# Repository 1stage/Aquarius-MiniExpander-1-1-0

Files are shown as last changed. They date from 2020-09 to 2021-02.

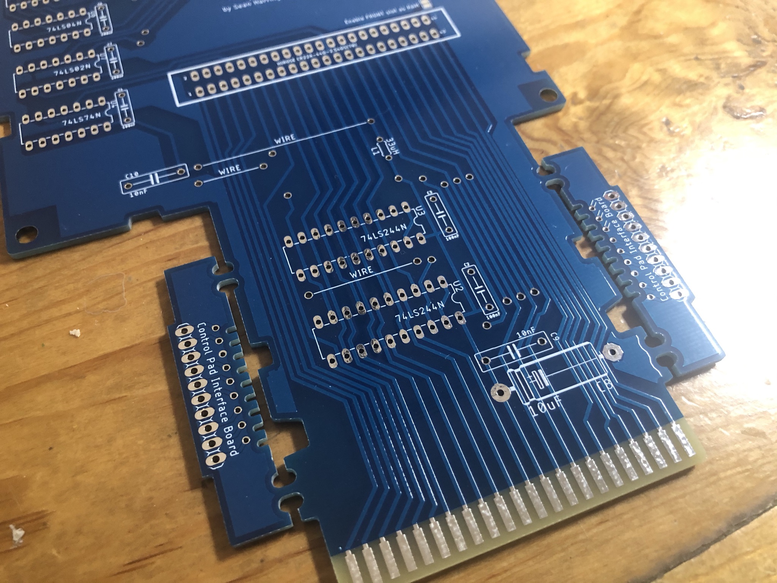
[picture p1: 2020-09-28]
images/IMG_6342.JPEG

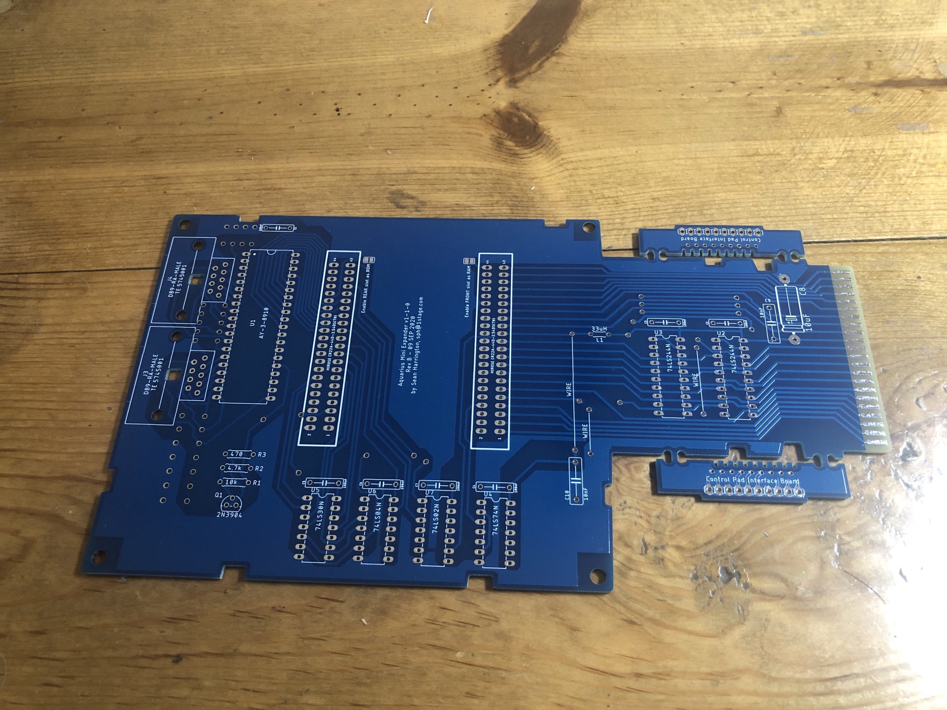
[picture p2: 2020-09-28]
images/IMG_6341.JPEG

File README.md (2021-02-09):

# Aquarius Mini Expander 1-1-0
Aquarius Mini Expander 1-1-0 - Rev C, 14 FEB 2021
 
by Sean P. Harrington, sph@1stage.com, http://aquarius.1stage.com
 
## Background
Since the Aquarius doesn't do much on it's own, and playing games on the chicklet keyboard is annoying, adding the functionality of the Mini Expander is essential. The Mini Expander expands the sounds to three voices, adds both a RAM and cartridge ROM expansion slot, and has ports for the Aquarius control pads. But since many Aquarius users DON'T have easy access to these devices, particularly in Europe, it was essential that this PCB be made available. 

## Purpose
The purpose of this project is to document the stock Aquarius Mini Expander, both in schematic form and in board layout. An excellent document from Radofin exists that records the original schematic for the device, and it was used to verify the components and layout of this project, but there are a few, minor discrepancies that have been corrected based on ACTUAL board layout. 

Also, this board serves as a useful prototype for how the expansion bus can be used on the Aquarius. By observing how the AY-3-8910 sound/IO chip is interfaced to the address and data bus, users who want to create their own expansion device could do so. Since it is already a very simple device (only about 25 components), the large footprint of the board could be improved through smaller SMD components and better trace routing, leaving plenty of room for additional functionality within the original (or modified) Mini Expander case.

To that end, an additional header for AY-3-8910 I/O has been added, along with detailed silkscreen markings on both the new header and the upper Expansion Slot so that hobbyists can experiment with creating their own expansions to the Aquarius. A reminder that the Expansion Slot pins are NOT like GPIO pins on an Arduino or Raspberry Pi. A0 does NOT mean analog pin zero, and D0 does NOT mean digital pin zero (nor any of the others). If you want to create your own I/O procedures, use the IO pins on the AY-3-8910 instead.

## Bill of Materials
https://docs.google.com/spreadsheets/d/1Fgy7V73wTicvzhZblFc1MAg1R4uz7tYPBy140xyRtXA	

## Components
* Aquarius Mini Expander v1-1-0 PCB Rev B, 09 SEP 2020
* Electronic components (listed in BOM above)
* 3D printed parts
  * Aquarius Mini Expander v1-1-0 case BOTTOM
  * Aquarius Mini Expander v1-1-0 case TOP (in development)
  * Aquarius Mini Expander v1-1-0 case TRAP_FRONT (in development)
  * Aquarius Mini Expander v1-1-0 case TRAP_REAR (in development)
* Assembly screws (to be specified later)
* Trap Door springs (to be specified later)
* Trap Door hinges (to be specified later)

## Caveats
* This project does **not incorporate** any new functionality. Users who want to add functionality may fork this project on their own.
  * SD Card read/write is not implemented, such as on the Micro Expander, a project developed by Bruce Abbott
  * A RAM expansion device is not included, such as the 32kb RAM Cartridge, a product developed by Jay Snellen, III
  * A cartridge ROM expansion device is not included, such as the AquariCart, a product developed by Jay Snellen, III
  * Switchable use of ATARI or SEGA joysticks (despite the same DB9 plugs)
* For users who want to use RAM or ROM in either cartridge slot, jumper pads (solder) have been added to connect pin 34 (rear slot) and/or pin 44 (front slot) to GND. Use this at your own discretion, but understand that you can't insert two ROM cartridges and expect them to work. Using two RAM cartridges could theoretically work, but it has not been tested.
* To maintain original layout, the three interconnect wires are not incorporated into the PCB. They are indicated as "WIRE" on the PCB, which should be bridged with 22 gauge solid core, insulated wire.
* The L1 choke/line filter (33uH) is difficult to source. Users may simply bridge this gap with 22 gauge solid core wire, or they can use a 0 ohm ferrite bead.
* Two of the small Control Pad interface boards are included as breakaways on either side of the narrow part of the board. These must be removed before the Mini Expander PCB can fit in the stock plastic shell. These small interface boards are used to transition the nine wires in the joystick cable to the mylar conductive pad used in the Control Pads.

## FAQs
* Where can I get the PCBs?
  * https://www.pcbway.com/project/shareproject/Aquarius_Computer_Mini_Expander_PCB.html
* Will you build me a Mini Expander? I'll pay you!
  * I won't (WAY too much to do), but it's not too difficult to do yourself. Also, there are some in the Aquarius community who can build one for you.
* Where can I get a case for this?
  * 3D print one yourself by exploring the 3d folder of the project. I haven't had time to create the top half (there are some intricate trap-door things to model), but maybe someone in the community will model one to fit?
* What about Control Pads?
  * There is a prototype for the Control Pads within the project, but I haven't had the time to take it beyond the prototype phase. This is open source, so have at it!
* How is this project different from the Micro Expander?
  * Designed by Bruce Abbott, the Aquarius Micro Expander is similar to the Mini Expander in that it has an AY-3-8910 sound chip and a header for Control Pad input (NOT joystick ports, a pin header). The Micro Expander is different in that it has a 32k memory expansion in it, a USB port, a 3.5mm audio port, along with a custom ROM that features a PT3 music player, USB ROM reading access, and a customized version of BASIC. The down side is that it blocks the Expansion Port of the Aquarius, so cartridge-based ROM programs (SNAFU, Nightstalker, D&D etc.) can't be used (unless you have the ROM image to load through USB).
* Why can't I use the A00-A15 expansion pins as analog input/output, or the D00-D15 as digital input/output for my Arduino experiments?
  * First of all, these pins are NOT analog and digital input/output pins! They are DIRECTLY connected to the **address** bus and the **data** bus (hence the A00 or D00 markings). Unless you know how the timings of these busses work, you're more than likely going to damage your Aquarius. If you want to experiment safely with TTL level inputs and outputs, use the IOA0-IOA7 or IOB0-IOB7 pins on the AY-3-8910 header instead.

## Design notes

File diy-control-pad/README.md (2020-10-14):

# DIY Aquarius Control Pad 1-1-0x
DIY Aquarius Control Pad 1-1-0x, 11 OCT 2020
 
by Sean P. Harrington, sph@1stage.com, http://aquarius.1stage.com
 
## Purpose
While reverse engineering the Mini Expander, it became obvious very quickly that there was also a need for easy-to-make Control Pads for the Aquarius. Those, as many of my UK/EU friends have said, are rare as hen's teeth. The stock unit was designed to be SUPER cheap and SUPER easy to crank out in quantity, however, the processes used in making the conductive ink, flexible control boards for the joysticks are not easily recreatable by a casual maker or electronics enthusiast. So I designed these "fugly" control boards using inexpensive, easy to source through-hole tactile switches and LN4148 diodes, a PCB, and a commonly available Atari/Sega joystick extension cable. 

## Components
* DIY Aquarius Control Pad v1-1-0x PCB, 11 OCT 2020
* Electronic components
  * 22 @ 6mm through hole tactile switches
  * 42 @ 1N4148 diodes
* 6 foot / 2 meter Atari/Sega Joystick extension cable
* 3D printed parts
  * DIY Aquarius Control Pad v1-1-0x BASE
  * DIY Aquarius Control Pad v1-1-0x TOP
  * DIY Aquarius Control Pad v1-1-0x DISC
  * DIY Aquarius Control Pad v1-1-0x BUTTONS
* Assembly screws (to be specified later)

## Caveats
* None, right now...

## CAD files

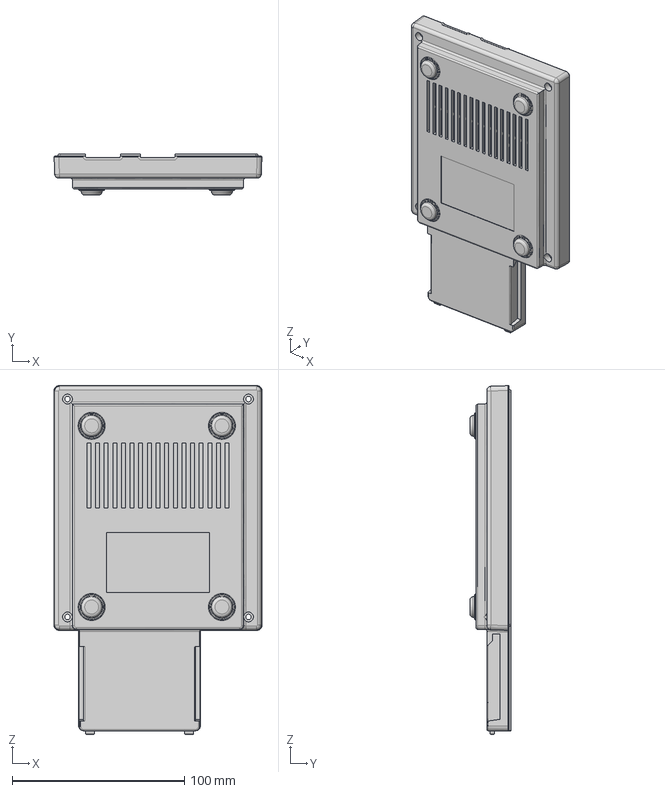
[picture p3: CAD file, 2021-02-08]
3d/v1-1-0 Mini Expander Base v4.iges
120.7 x 24.0 x 202.7 mm

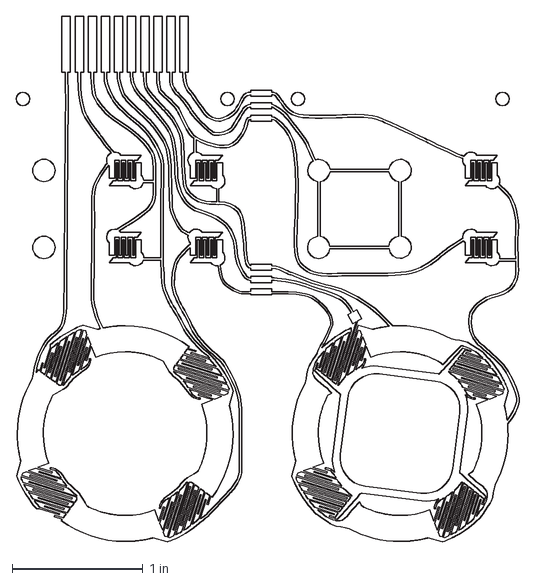
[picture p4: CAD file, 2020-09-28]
artwork/controller_circuit_01b_for_CUT.dxf
3.85 x 4.02 in

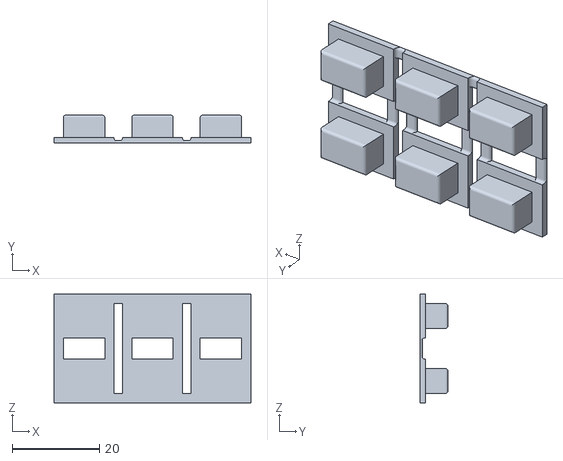
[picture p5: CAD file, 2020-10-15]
diy-control-pad/3d-case/diy_cp_buttons.stl
45.2 x 6.35 x 25.0

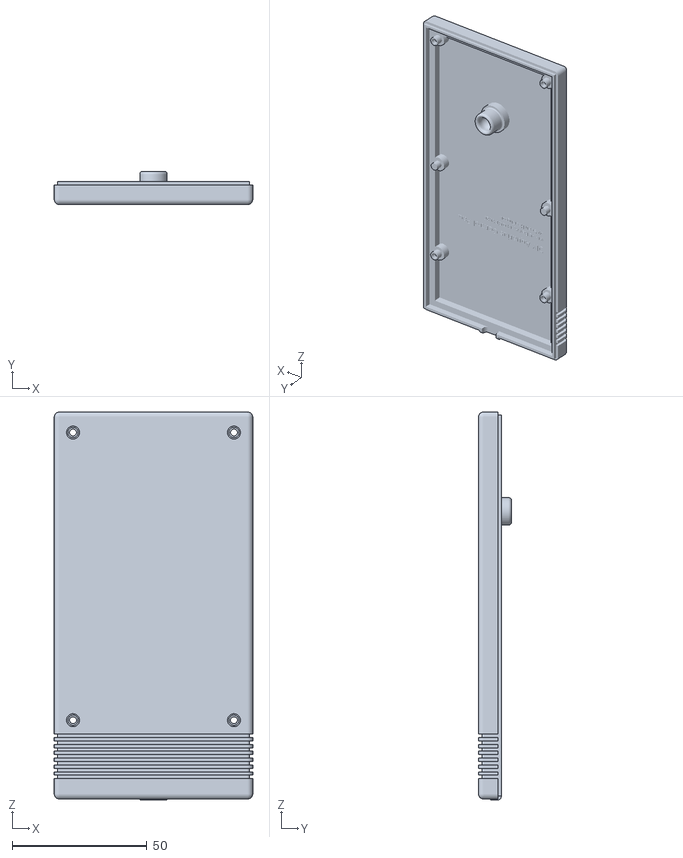
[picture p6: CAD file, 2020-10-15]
diy-control-pad/3d-case/diy_cp_base.stl
73.7 x 12.3 x 143.9

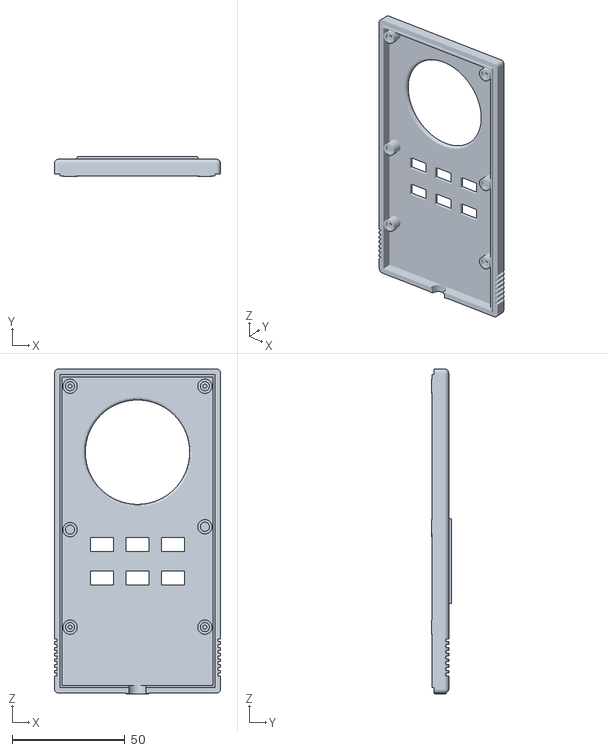
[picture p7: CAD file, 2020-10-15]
diy-control-pad/3d-case/diy_cp_top.stl
73.7 x 8.99 x 143.9

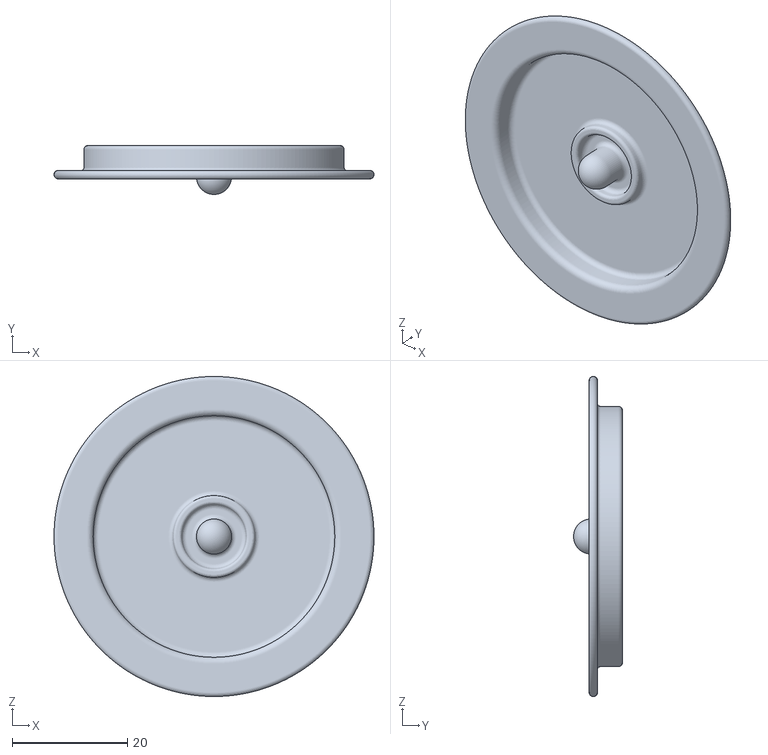
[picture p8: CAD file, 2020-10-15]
diy-control-pad/3d-case/diy_cp_disc.stl
55.5 x 8.48 x 55.5

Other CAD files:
3d/mini_expander_case_BOTTOM.stl

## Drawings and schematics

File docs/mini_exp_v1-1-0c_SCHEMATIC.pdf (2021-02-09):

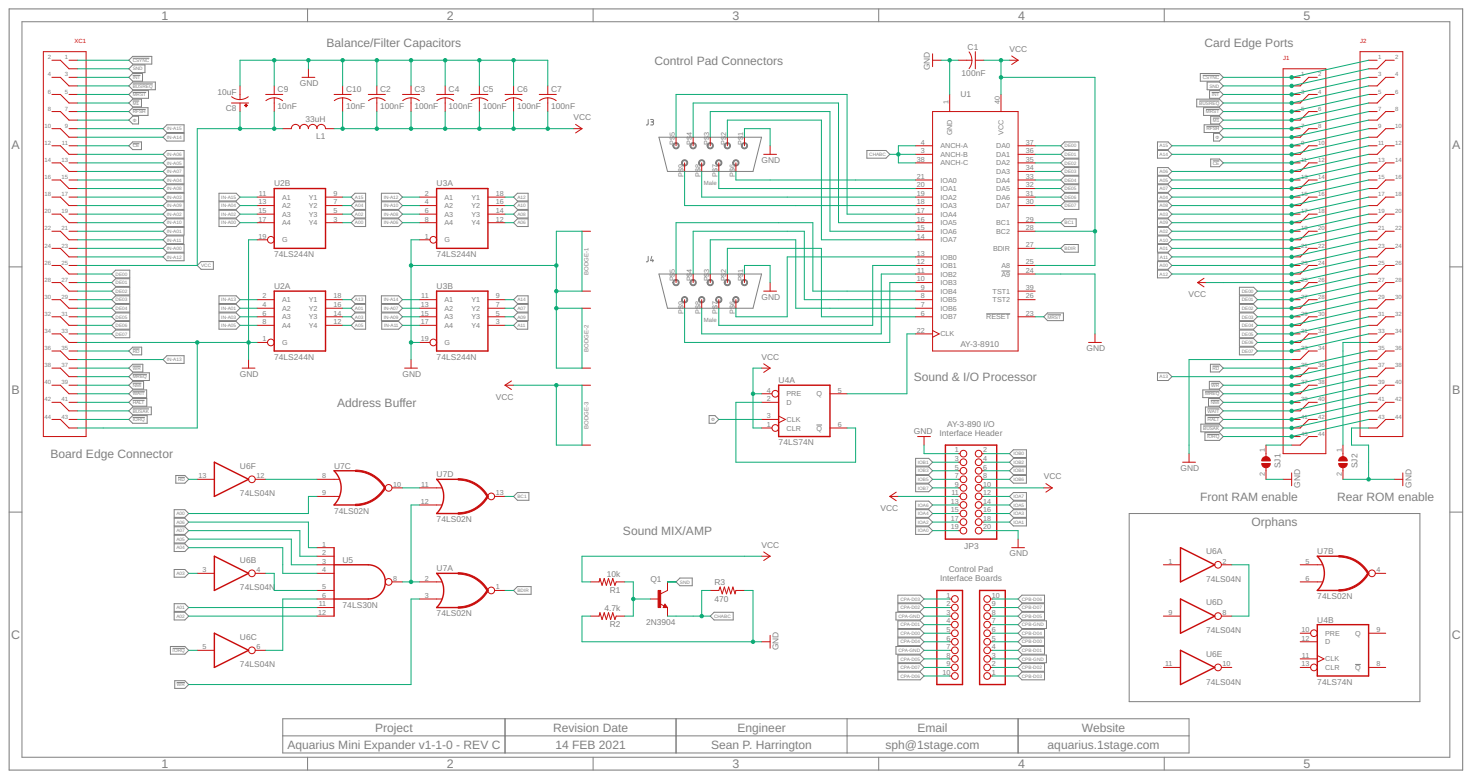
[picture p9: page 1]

CPA-D03 CPA-D02 CPA-GND

CPB-D06 CPB-D07 CPB-D05 CPB-GND

Project | Revision Date | Engineer | Email | Website

Aquarius Mini Expander v1-1-0 - REV C | 14 FEB 2021 | Sean P. Harrington | sph@1stage.com | aquarius.1stage.com

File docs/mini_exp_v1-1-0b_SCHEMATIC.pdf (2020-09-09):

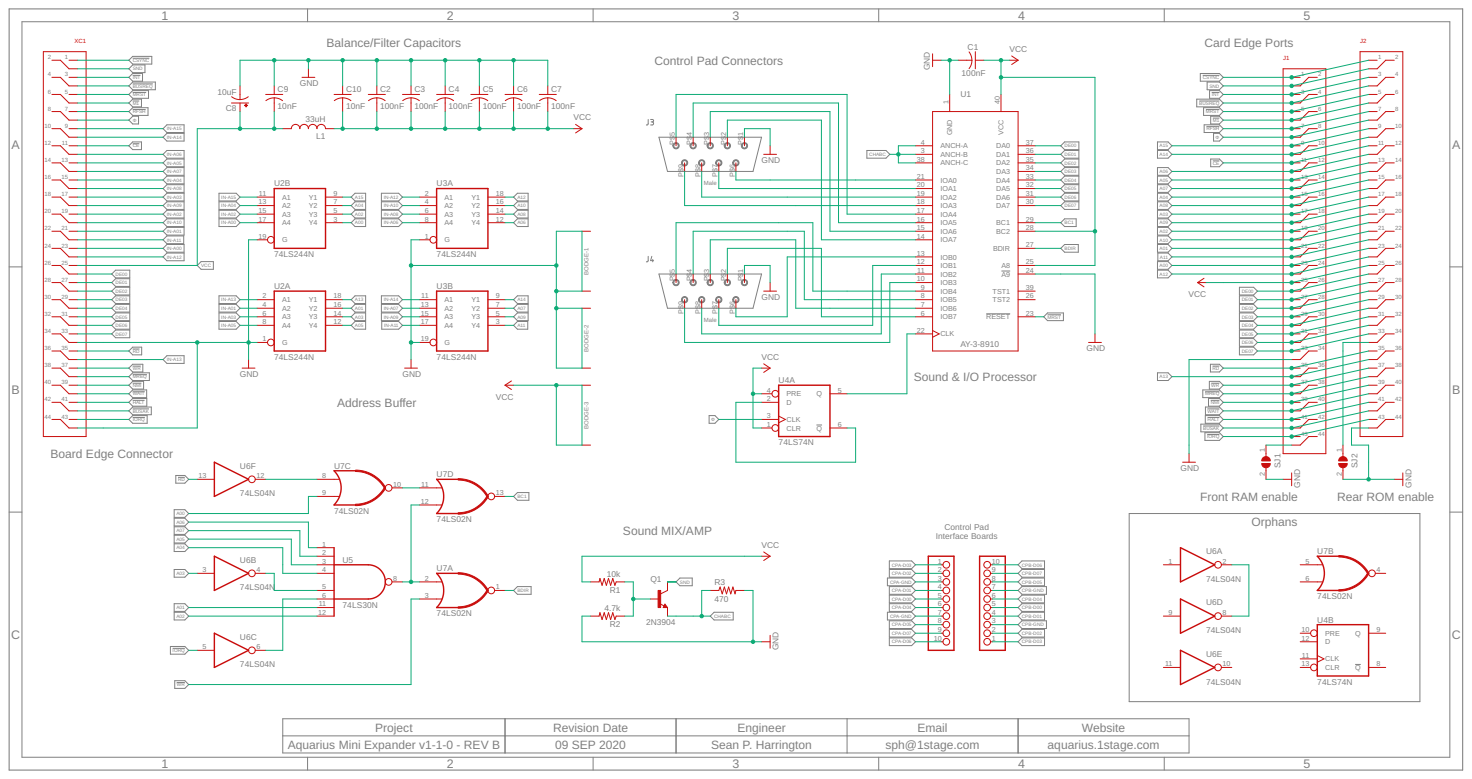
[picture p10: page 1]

CPA-D03 CPA-D02 CPA-GND

CPB-D06 CPB-D07 CPB-D05 CPB-GND

Project | Revision Date | Engineer | Email | Website

Aquarius Mini Expander v1-1-0 - REV B | 09 SEP 2020 | Sean P. Harrington | sph@1stage.com | aquarius.1stage.com

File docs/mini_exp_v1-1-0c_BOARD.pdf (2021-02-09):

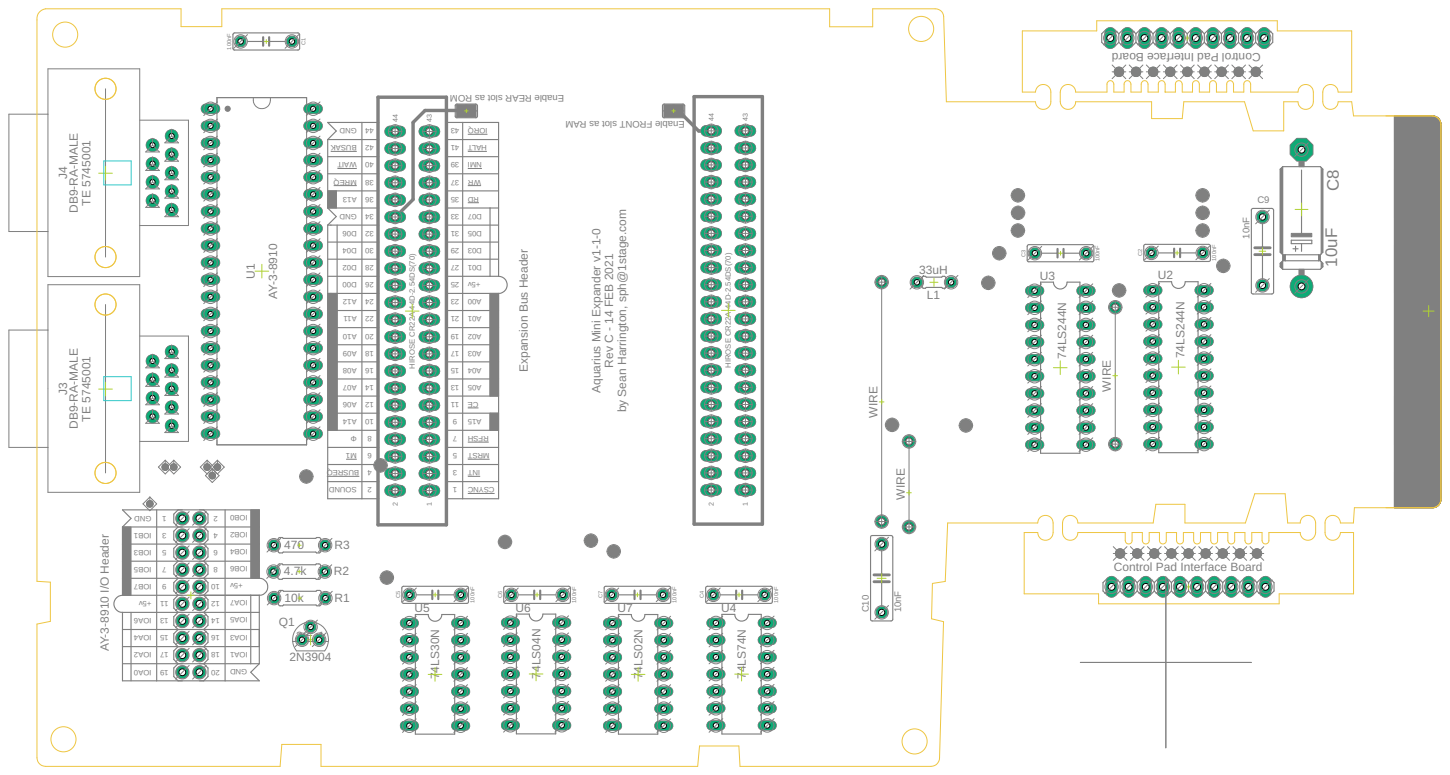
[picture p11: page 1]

Aquarius Mini Expander v1-1-0 Rev C - 14 FEB 2021 by Sean Harrington, sph@1stage.com MORsat ol s RAERel banE MARsat ol s TNORF el banE dr aoB ecafr et nI daPl ort no C Control Pad Interface Board CNYSC TNI TSRM HSFR 51A EC50A 40A 30A 20A 10A 00A v5+ 10 D 30 D 50 D 70 D DRR W I MN TLAH QROI DNUOS 341493735333139272523212917151311197531 4424048363432303826242220281614121018642 QERSUB 1 MΦ 41A 60A 70A 80A 90A 01A 11A 21A 00 D 20 D 40 D 60 D DNG 31A QERM TI A W KASUB DNG 0AOI 91 2AOI 71 4AOI 51 6AOI 31 v5+ 11 7BOI 9 5BOI 7 3BOI 5 1BOI 3 DNG 1 0281614121018642 DNG 1AOI 3AOI 5AOI 7AOI v5+ 6BOI 4BOI 2BOI 0BOI Expansion Bus Header AY-3-8910 I/O Header DB9-RA-MALE TE 5745001 J4 DB9-RA-MALE TE 5745001 J3 21 4443 HIROSE CR22A-44D-2.54DS(70) 21 4443 HIROSE CR22A-44D-2.54DS(70) WIRE WIRE WIRE 2 3 1 U1 AY-3-8910 U3 74LS244N U4 74LS74N U2 74LS244N U7 74LS02N U6 74LS04N U5 74LS30N 10k R1 4.7k R2 470 R3 C8 10uF C1 100nF C3 100nF C2 100nF C5 100nF C6 100nF C7 100nF C4 100nF C9 10nF C10 10nF L1 33uH Q12N3904

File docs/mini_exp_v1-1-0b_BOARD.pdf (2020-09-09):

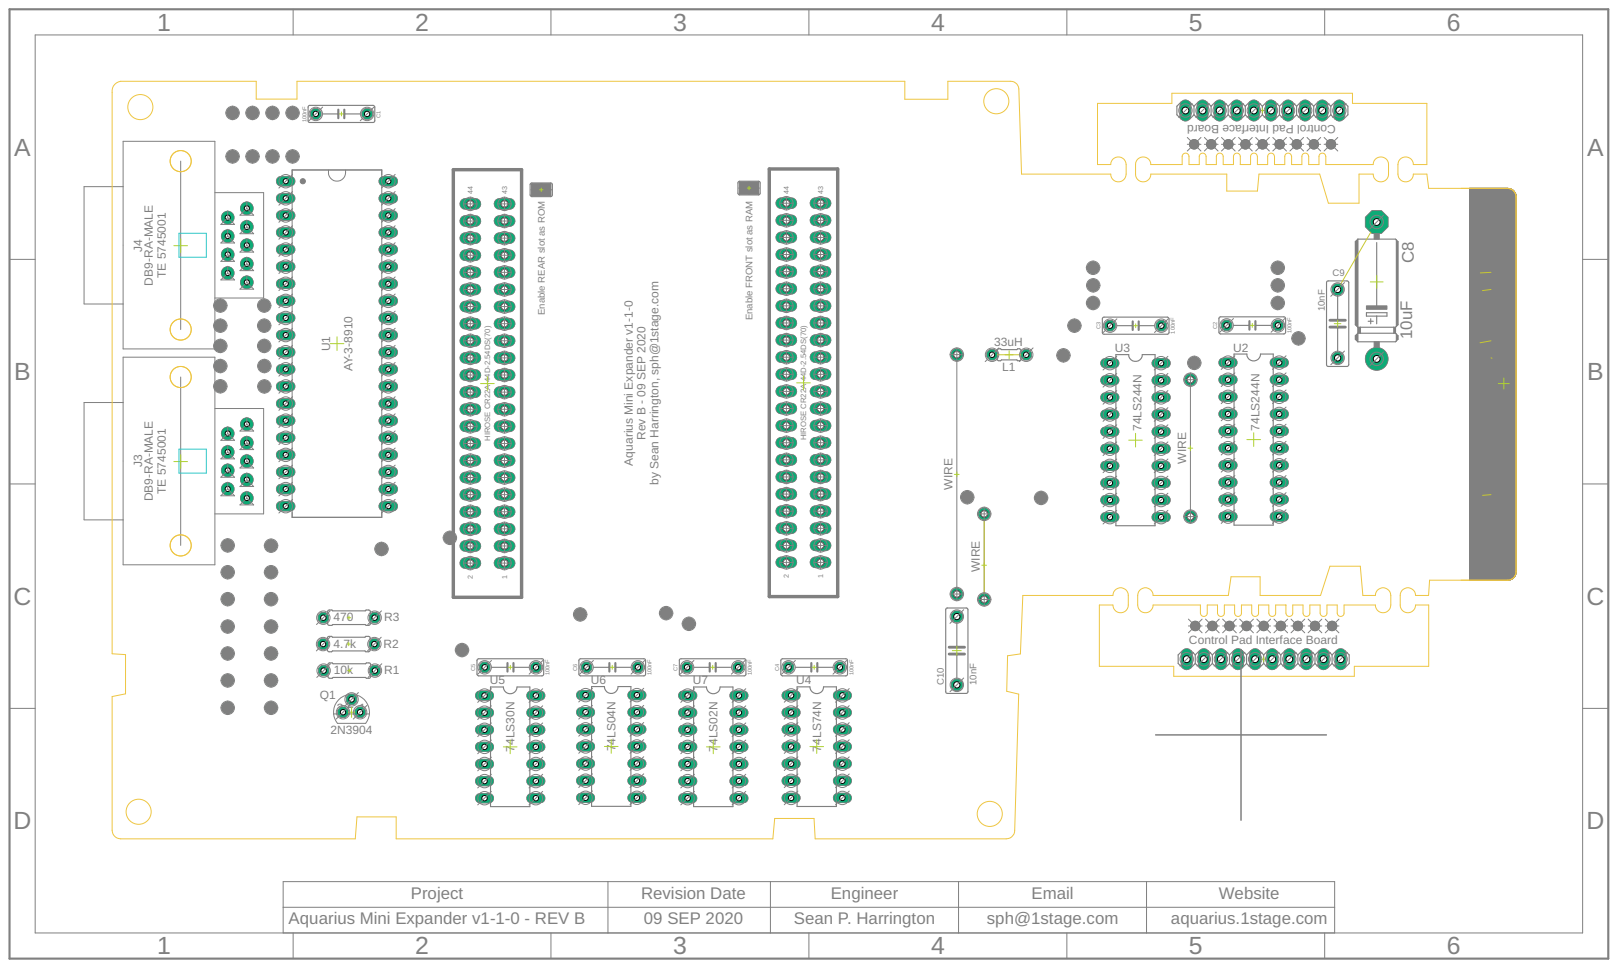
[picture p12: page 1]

Aquarius Mini Expander v1-1-0 Rev B - 09 SEP 2020 by Sean Harrington, sph@1stage.com Enable REAR slot as ROM Enable FRONT slot as RAM dr aoB ecafr et nI daPl ort no C Control Pad Interface Board DB9-RA-MALE TE 5745001 J4 DB9-RA-MALE TE 5745001 J3 21 4443 HIROSE CR22A-44D-2.54DS(70) 21 4443 HIROSE CR22A-44D-2.54DS(70) WIRE WIRE WIRE 2 3 1 U1 U3 U4 U2 U5 U6 U7 R1 R2R3 C8 C1 C3C2 C5 C6 C7 C4 C9 C10 L1 Q1 AY-3-8910 74LS244N 74LS74N 74LS244N 74LS02N 74LS04N 74LS30N 10k 4.7k 470 10uF 100nF 100nF 100nF 100nF 100nF 100nF 100nF 10nF 10nF 33uH 2N3904 ABCD 1 2 3 4 5 6 ABCD 1 2 3 4 5 6 Project Revision Date Engineer Email Website Aquarius Mini Expander v1-1-0 - REV B 09 SEP 2020 Sean P. Harrington sph@1stage.com aquarius.1stage.com

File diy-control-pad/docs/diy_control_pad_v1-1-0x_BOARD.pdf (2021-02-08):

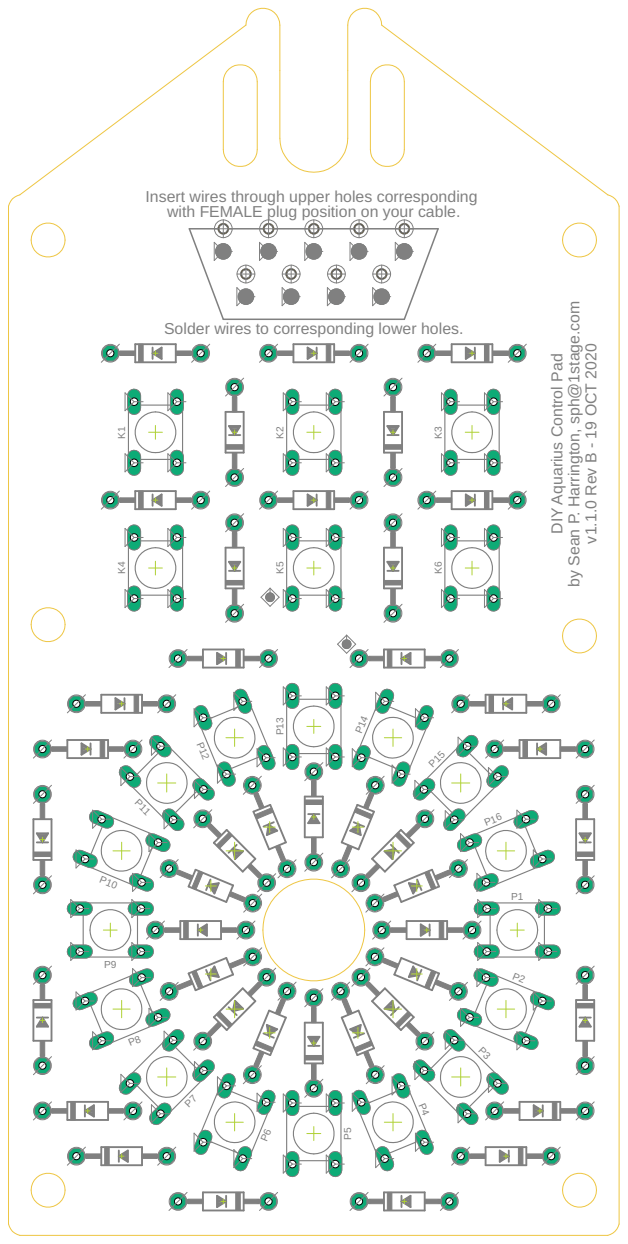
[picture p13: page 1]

Insert wires through upper holes corresponding with FEMALE plug position on your cable.

Solder wires to corresponding lower holes.

by Sean P. Harrington, sph@1stage.com

DIY Aquarius Control Pad

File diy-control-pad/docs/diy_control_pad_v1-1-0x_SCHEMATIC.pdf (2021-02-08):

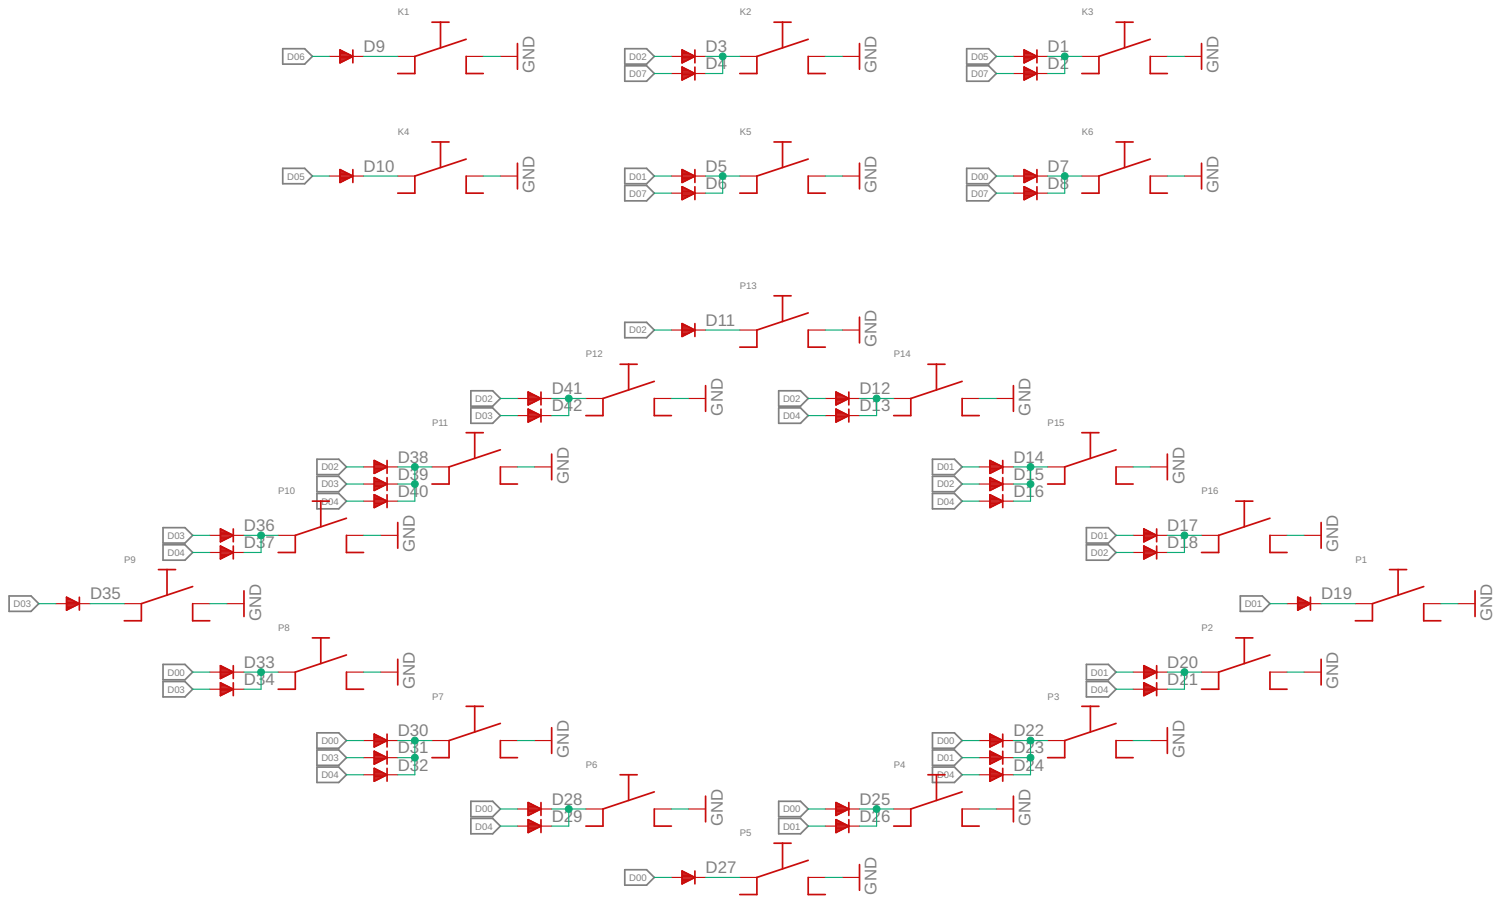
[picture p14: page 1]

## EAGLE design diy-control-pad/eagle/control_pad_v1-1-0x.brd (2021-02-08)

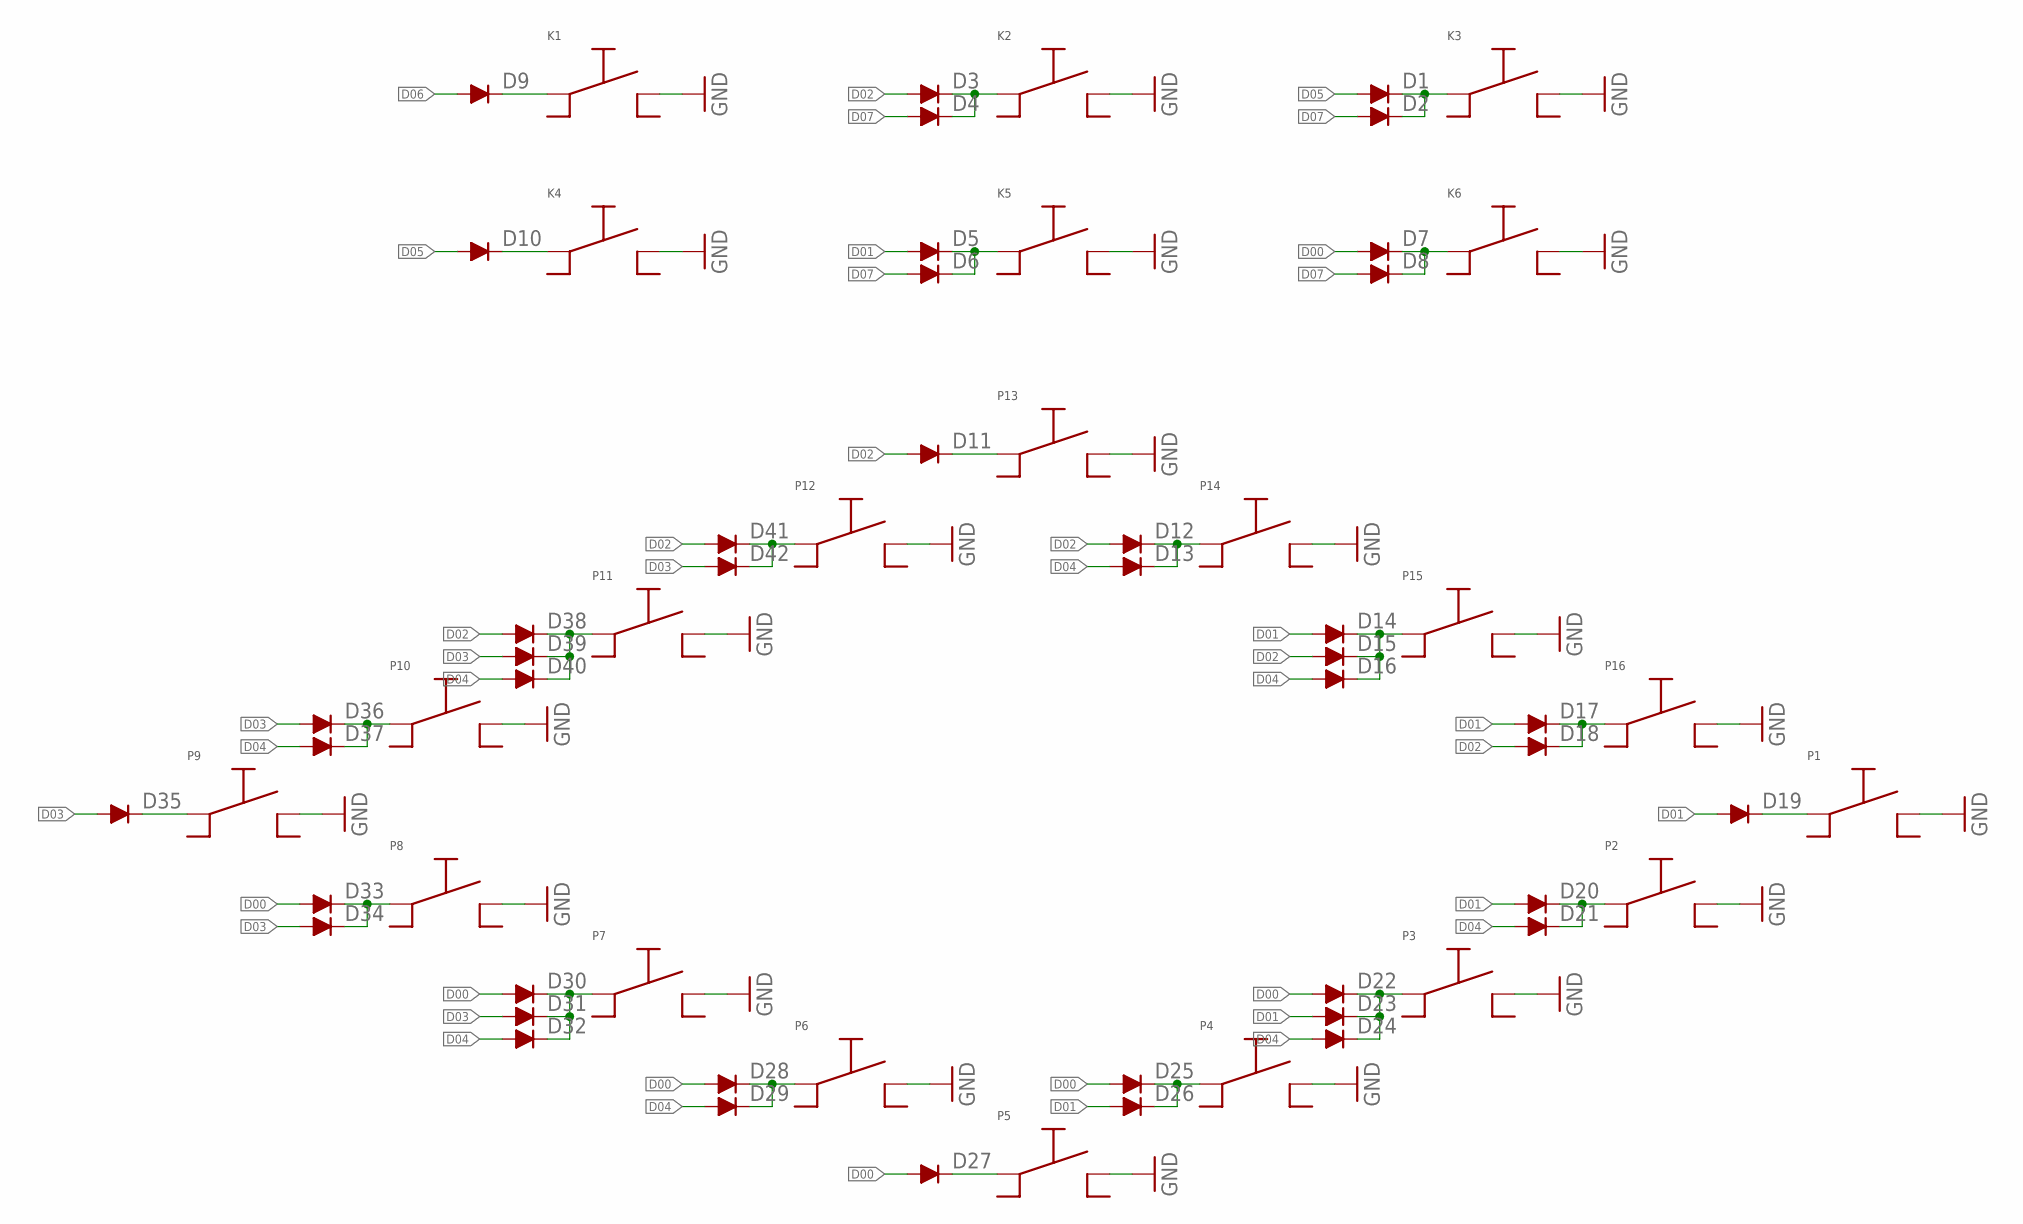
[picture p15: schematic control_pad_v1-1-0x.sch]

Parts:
D1, D2, D3, D4, D5, D6, D7, D8, D9, D10, D11, D12, D13, D14, D15, D16, D17, D18, D19, D20, D21, D22, D23, D24, D25, D26, D27, D28, D29, D30, D31, D32, D33, D34, D35, D36, D37, D38, D39, D40, D41, D42: 1N4148; DO35-10
K1, K2, K3, K4, K5, K6: TACT-SPST
P1, P2, P3, P4, P5, P6, P7, P8, P9, P10, P11, P12, P13, P14, P15, P16: TACT-SPST

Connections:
D00: D7.A, D22.A, D25.A, D27.A, D28.A, D30.A, D33.A
D01: D5.A, D14.A, D17.A, D19.A, D20.A, D23.A, D26.A
D02: D3.A, D11.A, D12.A, D15.A, D18.A, D38.A, D41.A
D03: D31.A, D34.A, D35.A, D36.A, D39.A, D42.A
D04: D13.A, D16.A, D21.A, D24.A, D29.A, D32.A, D37.A, D40.A
D05: D1.A, D10.A
D06: D9.A
D07: D2.A, D4.A, D6.A, D8.A
GND: K1.P$2, K1.P$4, K2.P$2, K2.P$4, K3.P$2, K3.P$4, K4.P$2, K4.P$4, K5.P$2, K5.P$4, K6.P$2, K6.P$4, P1.P$2, P1.P$4, P2.P$2, P2.P$4, P3.P$2, P3.P$4, P4.P$2, P4.P$4, P5.P$2, P5.P$4, P6.P$2, P6.P$4, P7.P$2, P7.P$4, P8.P$2, P8.P$4, P9.P$2, P9.P$4, P10.P$2, P10.P$4, P11.P$2, P11.P$4, P12.P$2, P12.P$4, P13.P$2, P13.P$4, P14.P$2, P14.P$4, P15.P$2, P15.P$4, P16.P$2, P16.P$4
unnamed: D9.C, K1.P$1, K1.P$3
unnamed: D10.C, K4.P$1, K4.P$3
unnamed: D11.C, P13.P$1, P13.P$3
unnamed: D1.C, D2.C, K3.P$1, K3.P$3
unnamed: D3.C, D4.C, K2.P$1, K2.P$3
unnamed: D5.C, D6.C, K5.P$1, K5.P$3
unnamed: D7.C, D8.C, K6.P$1, K6.P$3
unnamed: D14.C, D15.C, D16.C, P15.P$1, P15.P$3
unnamed: D12.C, D13.C, P14.P$1, P14.P$3
unnamed: D19.C, P1.P$1, P1.P$3
unnamed: D17.C, D18.C, P16.P$1, P16.P$3
unnamed: D20.C, D21.C, P2.P$1, P2.P$3
unnamed: D22.C, D23.C, D24.C, P3.P$1, P3.P$3
unnamed: D25.C, D26.C, P4.P$1, P4.P$3
unnamed: D27.C, P5.P$1, P5.P$3
unnamed: D28.C, D29.C, P6.P$1, P6.P$3
unnamed: D30.C, D31.C, D32.C, P7.P$1, P7.P$3
unnamed: D33.C, D34.C, P8.P$1, P8.P$3
unnamed: D35.C, P9.P$1, P9.P$3
unnamed: D36.C, D37.C, P10.P$1, P10.P$3
unnamed: D38.C, D39.C, D40.C, P11.P$1, P11.P$3
unnamed: D41.C, D42.C, P12.P$1, P12.P$3

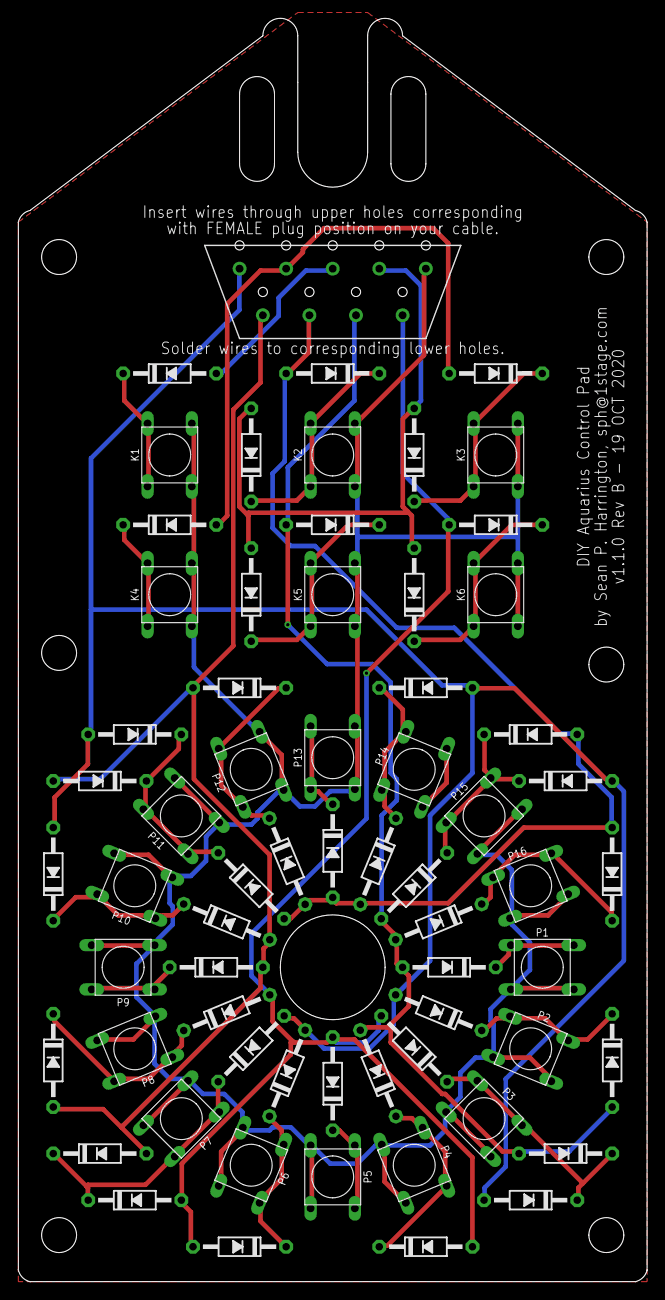
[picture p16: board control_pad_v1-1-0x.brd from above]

Board: 2 copper layers, 68.6 x 137.8 mm, 64 parts (0 on the bottom side), 30 nets.

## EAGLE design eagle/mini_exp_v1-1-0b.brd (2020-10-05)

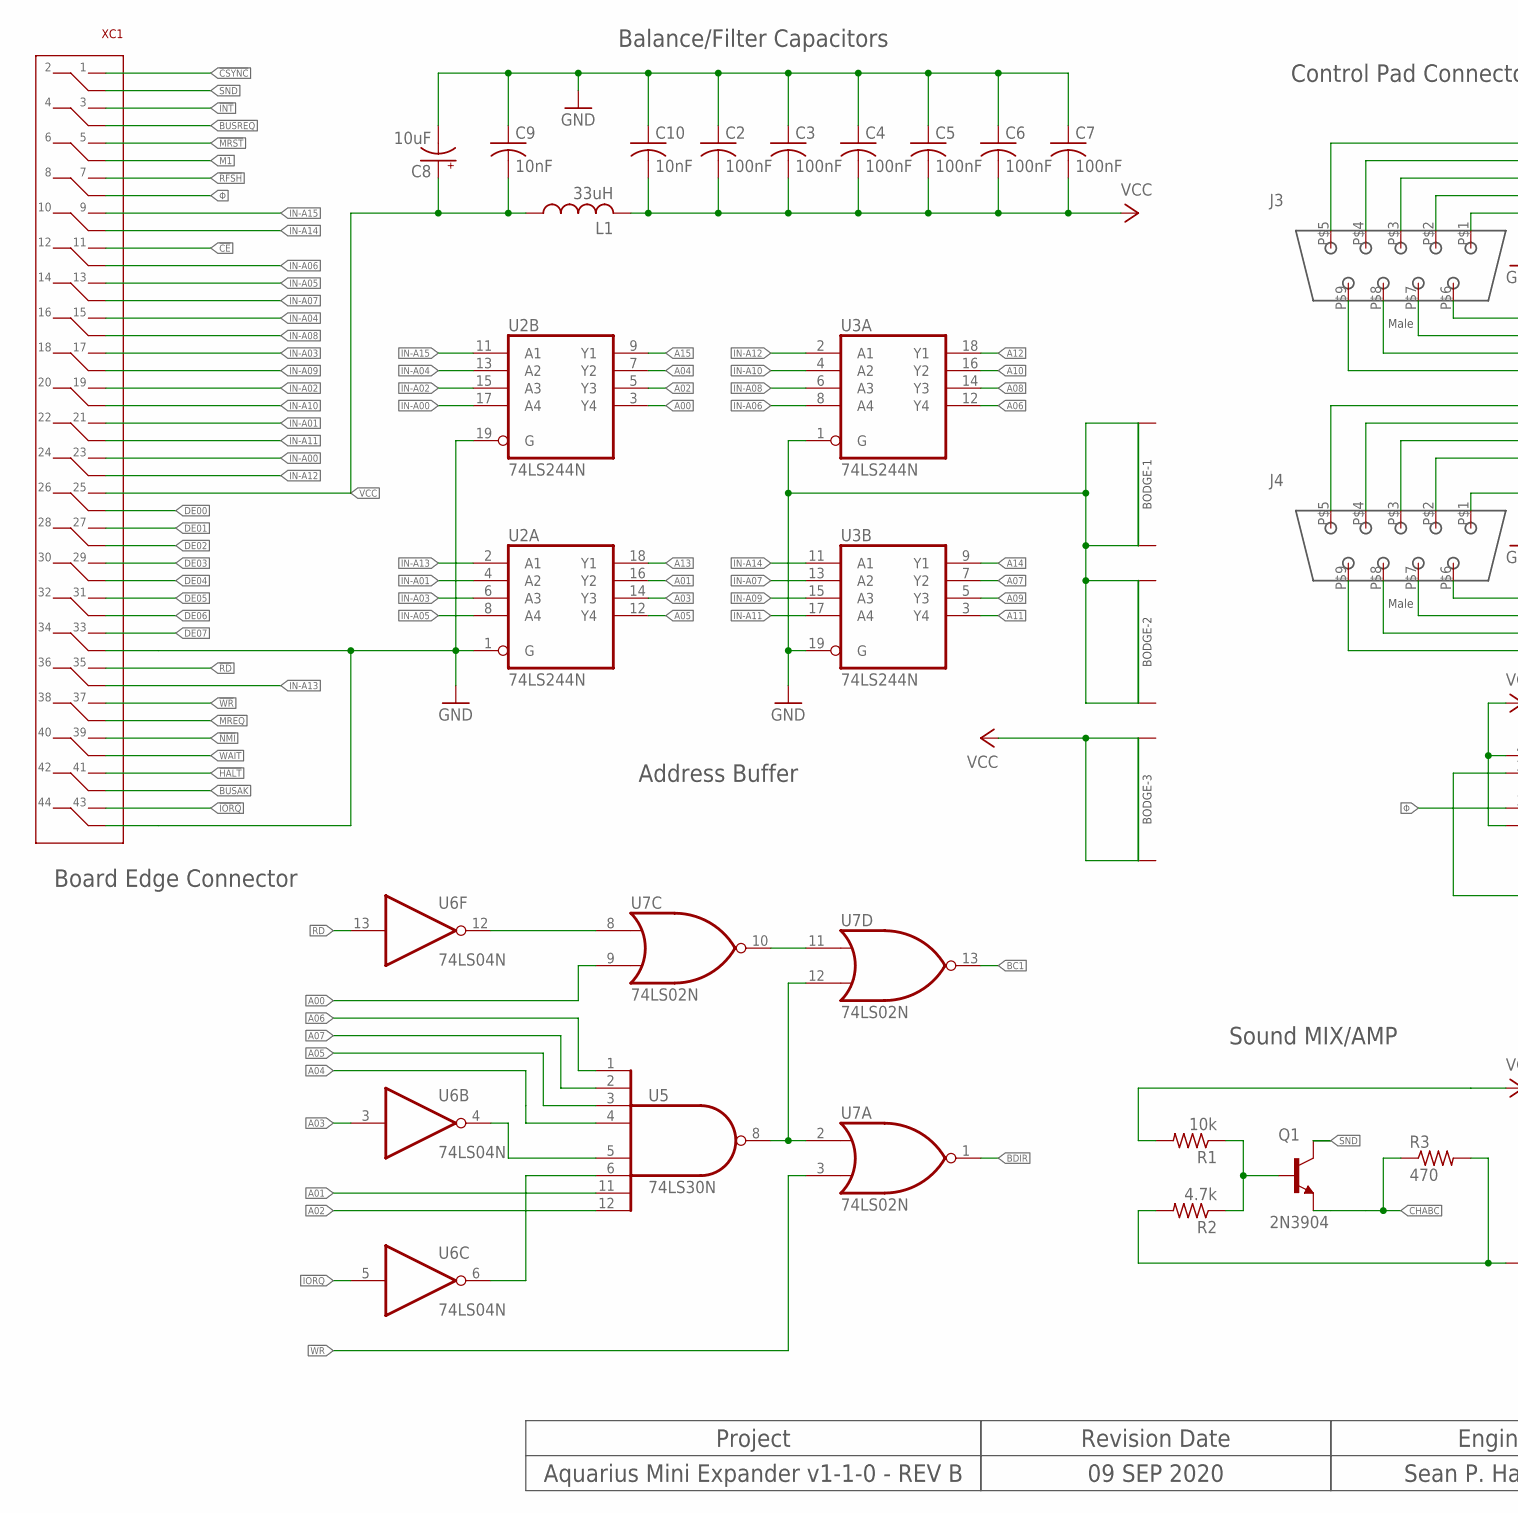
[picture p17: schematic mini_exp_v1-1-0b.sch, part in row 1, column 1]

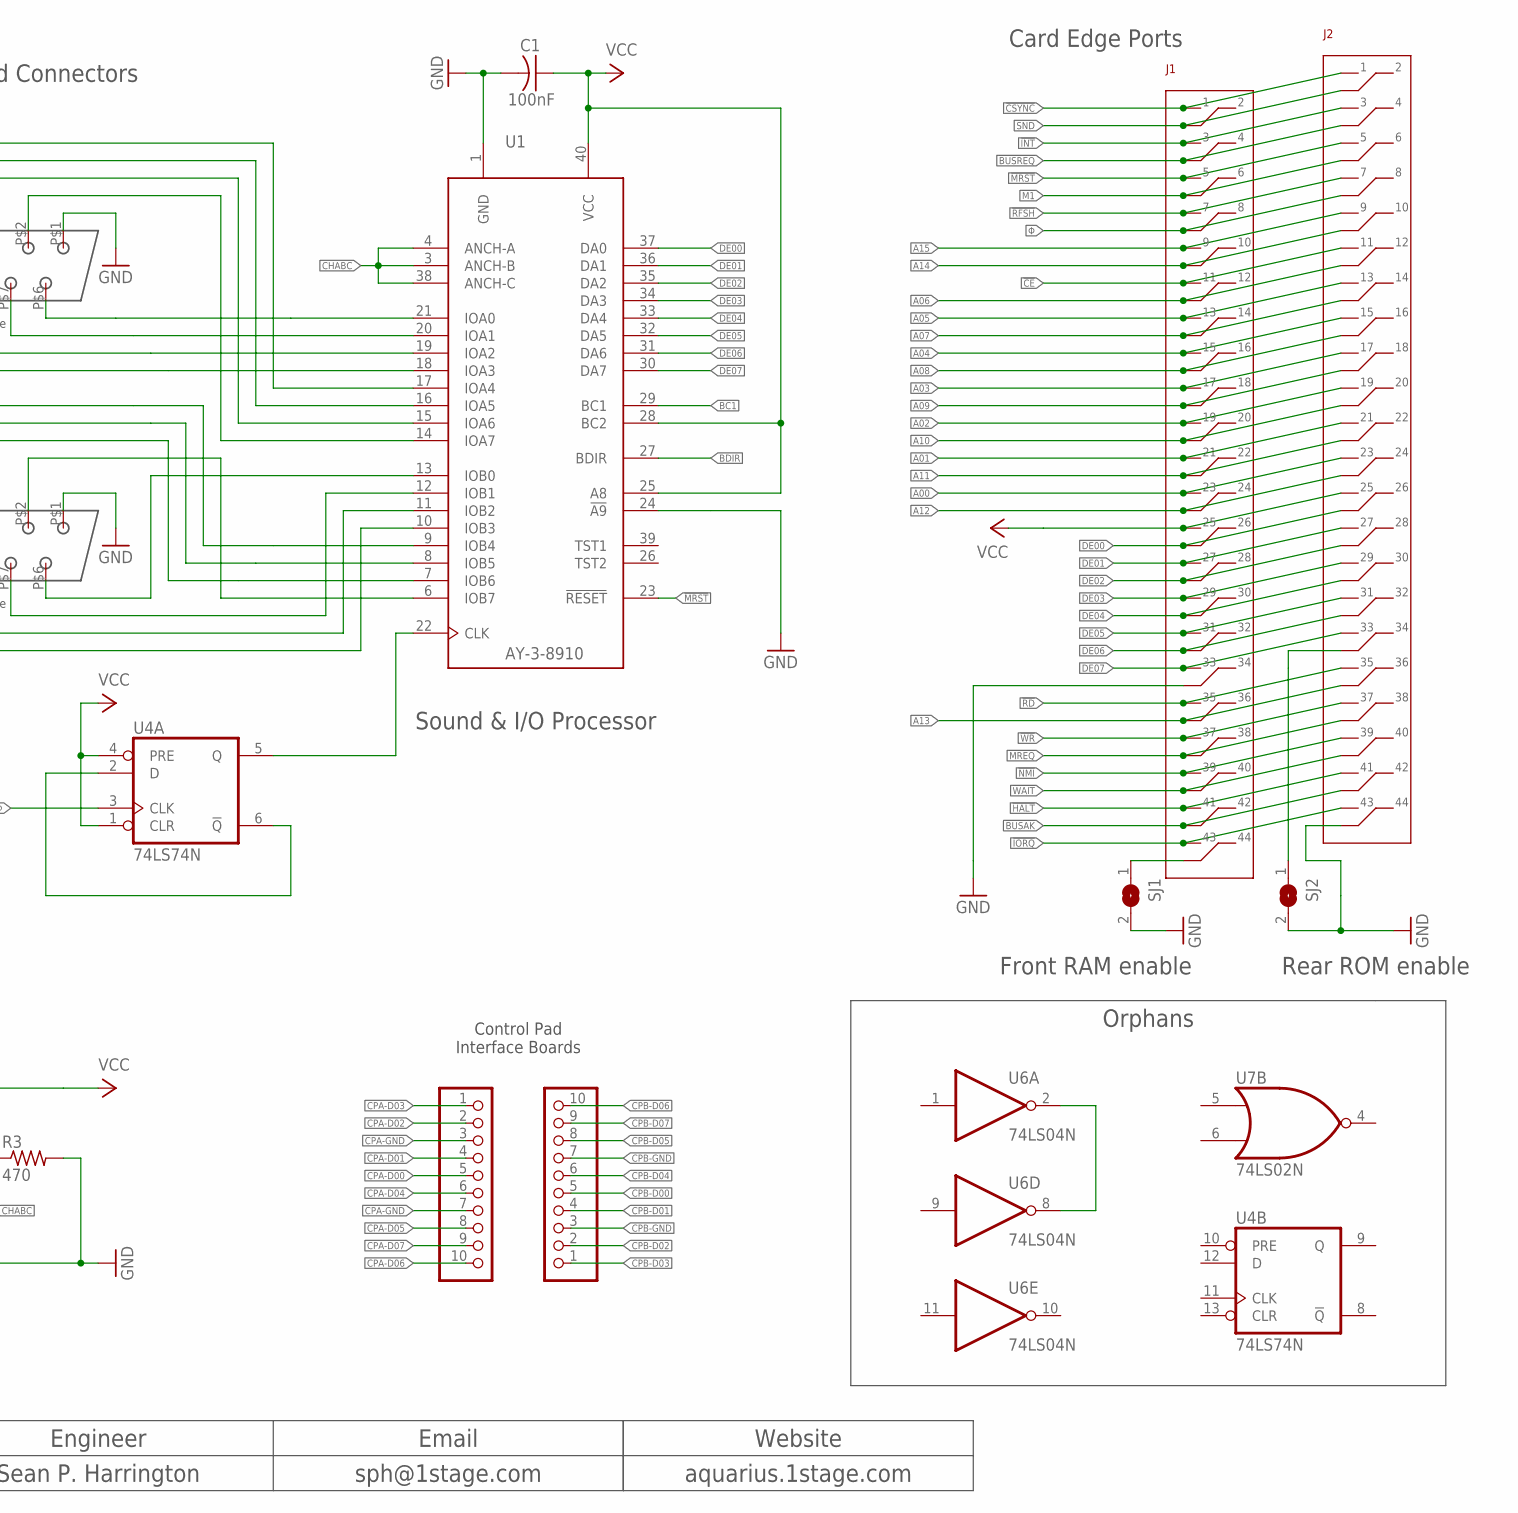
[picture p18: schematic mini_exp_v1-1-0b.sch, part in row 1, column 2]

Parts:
C1, C2, C3, C4, C5, C6, C7: 100nF; C050-025X095
C8: 10uF; E22-6
C9, C10: 10nF; C075-032X103
J1, J2: CR22A-44D-2.54DS(70)STRAIGHT; CR22A-44D-2.54DS(70)
J3, J4: DB9-MALE-RA
JP1, JP2: PINHD-1X10; 1X10
L1: 33uH; 0204/5
Q1: 2N3904; TO92
R1: 10k; 0207/7
R2: 4.7k; 0207/7
R3: 470; 0207/7
SJ1, SJ2: SJ
U1: AY-3-8910; RAD38910-DIL40-6
U2, U3: 74LS244N; DIL20
U4: 74LS74N; DIL14
U5: 74LS30N; DIL14
U6: 74LS04N; DIL14
U7: 74LS02N; DIL14
XC1: AQ-CART-EDGE
XX01: AQ-MX-BODGE-1
XX02: AQ-MX-BODGE-2
XX03: AQ-MX-BODGE-3

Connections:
!BUSAK: J1.P$42 (X42), J2.P$42 (X42), XC1.P$42 (X42)
!BUSREQ: J1.P$4 (X4), J2.P$4 (X4), XC1.P$4 (X4)
!CE: J1.P$11 (X11), J2.P$11 (X11), XC1.P$11 (X11)
!CSYNC: J1.P$1 (X1), J2.P$1 (X1), XC1.P$1 (X1)
!HALT: J1.P$41 (X41), J2.P$41 (X41), XC1.P$41 (X41)
!INT: J1.P$3 (X3), J2.P$3 (X3), XC1.P$3 (X3)
!IORQ: J1.P$43 (X43), J2.P$43 (X43), U6.5 (I), XC1.P$43 (X43)
!M1: J1.P$6 (X6), J2.P$6 (X6), XC1.P$6 (X6)
!MREQ: J1.P$38 (X38), J2.P$38 (X38), XC1.P$38 (X38)
!MRST: J1.P$5 (X5), J2.P$5 (X5), U1.23 (!RESET), XC1.P$5 (X5)
!NMI: J1.P$39 (X39), J2.P$39 (X39), XC1.P$39 (X39)
!RD: J1.P$35 (X35), J2.P$35 (X35), U6.13 (I), XC1.P$35 (X35)
!RFSH: J1.P$7 (X7), J2.P$7 (X7), XC1.P$7 (X7)
!WAIT: J1.P$40 (X40), J2.P$40 (X40), XC1.P$40 (X40)
!WR: J1.P$37 (X37), J2.P$37 (X37), U7.3 (I1), XC1.P$37 (X37)
A00: J1.P$23 (X23), J2.P$23 (X23), U2.3 (Y4), U7.9 (I1)
A01: J1.P$21 (X21), J2.P$21 (X21), U2.16 (Y2), U5.11 (I6)
A02: J1.P$19 (X19), J2.P$19 (X19), U2.5 (Y3), U5.12 (I7)
A03: J1.P$17 (X17), J2.P$17 (X17), U2.14 (Y3), U6.3 (I)
A04: J1.P$15 (X15), J2.P$15 (X15), U2.7 (Y2), U5.4 (I3)
A05: J1.P$13 (X13), J2.P$13 (X13), U2.12 (Y4), U5.3 (I2)
A06: J1.P$12 (X12), J2.P$12 (X12), U3.12 (Y4), U5.1 (I0)
A07: J1.P$14 (X14), J2.P$14 (X14), U3.7 (Y2), U5.2 (I1)
A08: J1.P$16 (X16), J2.P$16 (X16), U3.14 (Y3)
A09: J1.P$18 (X18), J2.P$18 (X18), U3.5 (Y3)
A10: J1.P$20 (X20), J2.P$20 (X20), U3.16 (Y2)
A11: J1.P$22 (X22), J2.P$22 (X22), U3.3 (Y4)
A12: J1.P$24 (X24), J2.P$24 (X24), U3.18 (Y1)
A13: J1.P$36 (X36), J2.P$36 (X36), U2.18 (Y1)
A14: J1.P$10 (X10), J2.P$10 (X10), U3.9 (Y1)
A15: J1.P$9 (X9), J2.P$9 (X9), U2.9 (Y1)
BC1: U1.29 (BC1), U7.13 (O)
BDIR: U1.27 (BDIR), U7.1 (O)
CHABC: Q1.3 (E), R3.1, U1.3 (ANCH-B), U1.4 (ANCH-A), U1.38 (ANCH-C)
CPA-D00: JP1.5
CPA-D01: JP1.4
CPA-D02: JP1.2
CPA-D03: JP1.1
CPA-D04: JP1.6
CPA-D05: JP1.8
CPA-D06: JP1.10
CPA-D07: JP1.9
CPA-GND: JP1.3, JP1.7
CPB-D00: JP2.5
CPB-D01: JP2.4
CPB-D02: JP2.2
CPB-D03: JP2.1
CPB-D04: JP2.6
CPB-D05: JP2.8
CPB-D06: JP2.10
CPB-D07: JP2.9
CPB-GND: JP2.3, JP2.7
DE00: J1.P$26 (X26), J2.P$26 (X26), U1.37 (DA0), XC1.P$26 (X26)
DE01: J1.P$27 (X27), J2.P$27 (X27), U1.36 (DA1), XC1.P$27 (X27)
DE02: J1.P$28 (X28), J2.P$28 (X28), U1.35 (DA2), XC1.P$28 (X28)
DE03: J1.P$29 (X29), J2.P$29 (X29), U1.34 (DA3), XC1.P$29 (X29)
DE04: J1.P$30 (X30), J2.P$30 (X30), U1.33 (DA4), XC1.P$30 (X30)
DE05: J1.P$31 (X31), J2.P$31 (X31), U1.32 (DA5), XC1.P$31 (X31)
DE06: J1.P$32 (X32), J2.P$32 (X32), U1.31 (DA6), XC1.P$32 (X32)
DE07: J1.P$33 (X33), J2.P$33 (X33), U1.30 (DA7), XC1.P$33 (X33)
GND: C1.2, C2.1, C3.1, C4.1, C5.1, C6.1, C7.1, C8.-, C9.1, C10.1, J1.P$34 (X34), J2.P$44 (X44), J3.P$1, J4.P$1, R2.2, R3.2, SJ1.2, SJ2.2, U1.1 (GND), U1.24 (!A9), U2.1 (G), U2.10 (GND), U2.19 (G), U3.1 (G), U3.10 (GND), U3.19 (G), U4.7 (GND), U5.7 (GND), U6.7 (GND), U7.7 (GND), XC1.P$34 (X34), XC1.P$44 (X44), XX01.P$1, XX01.P$2, XX02.P$1, XX02.P$2
IN-A00: U2.17 (A4), XC1.P$23 (X23)
IN-A01: U2.4 (A2), XC1.P$21 (X21)
IN-A02: U2.15 (A3), XC1.P$19 (X19)
IN-A03: U2.6 (A3), XC1.P$17 (X17)
IN-A04: U2.13 (A2), XC1.P$15 (X15)
IN-A05: U2.8 (A4), XC1.P$13 (X13)
IN-A06: U3.8 (A4), XC1.P$12 (X12)
IN-A07: U3.13 (A2), XC1.P$14 (X14)
IN-A08: U3.6 (A3), XC1.P$16 (X16)
IN-A09: U3.15 (A3), XC1.P$18 (X18)
IN-A10: U3.4 (A2), XC1.P$20 (X20)
IN-A11: U3.17 (A4), XC1.P$22 (X22)
IN-A12: U3.2 (A1), XC1.P$24 (X24)
IN-A13: U2.2 (A1), XC1.P$36 (X36)
IN-A14: U3.11 (A1), XC1.P$10 (X10)
IN-A15: U2.11 (A1), XC1.P$9 (X9)
unnamed: Q1.2 (B), R1.1, R2.1
unnamed: U6.2 (O), U6.8 (O)
unnamed: J1.P$44 (X44), SJ1.1
unnamed: J2.P$34 (X34), SJ2.1
unnamed: J4.P$6, U1.13 (IOB0)
unnamed: U7.10 (O), U7.11 (I0)
unnamed: U4.2 (D), U4.6 (!Q)
unnamed: U1.22 (CLK), U4.5 (Q)
unnamed: U5.8 (O), U7.2 (I0), U7.12 (I1)
unnamed: U6.12 (O), U7.8 (I0)
unnamed: U5.5 (I4), U6.4 (O)
unnamed: U5.6 (I5), U6.6 (O)
unnamed: J4.P$2, U1.6 (IOB7)
unnamed: J4.P$7, U1.12 (IOB1)
unnamed: J4.P$8, U1.11 (IOB2)
unnamed: J4.P$5, U1.9 (IOB4)
unnamed: J4.P$4, U1.8 (IOB5)
unnamed: J4.P$3, U1.7 (IOB6)
unnamed: J4.P$9, U1.10 (IOB3)
unnamed: J3.P$2, U1.14 (IOA7)
unnamed: J3.P$3, U1.15 (IOA6)
unnamed: J3.P$4, U1.16 (IOA5)
unnamed: J3.P$5, U1.17 (IOA4)
unnamed: J3.P$6, U1.21 (IOA0)
unnamed: J3.P$7, U1.20 (IOA1)
unnamed: J3.P$8, U1.19 (IOA2)
unnamed: J3.P$9, U1.18 (IOA3)
SND: J1.P$2 (X2), J2.P$2 (X2), Q1.1 (C), XC1.P$2 (X2)
VCC: C1.1, C2.2, C3.2, C4.2, C5.2, C6.2, C7.2, C8.+, C9.2, C10.2, J1.P$25 (X25), J2.P$25 (X25), L1.1, L1.2, R1.2, U1.25 (A8), U1.28 (BC2), U1.40 (VCC), U2.20 (VCC), U3.20 (VCC), U4.1 (CLR), U4.4 (PRE), U4.14 (VCC), U5.14 (VCC), U6.14 (VCC), U7.14 (VCC), XC1.P$25 (X25), XX03.P$1, XX03.P$2
Φ: J1.P$8 (X8), J2.P$8 (X8), U4.3 (CLK), XC1.P$8 (X8)

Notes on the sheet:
Orphans
Board Edge Connector
Card Edge Ports
Control Pad Connectors
Sound & I/O Processor
Sound MIX/AMP
Address Buffer
Balance/Filter Capacitors
Aquarius Mini Expander v1-1-0 - REV B
Project
09 SEP 2020
Revision Date
Sean P. Harrington
Engineer
aquarius.1stage.com
Website
Email
sph@1stage.com
Front RAM enable
Rear ROM enable
Control Pad Interface Boards

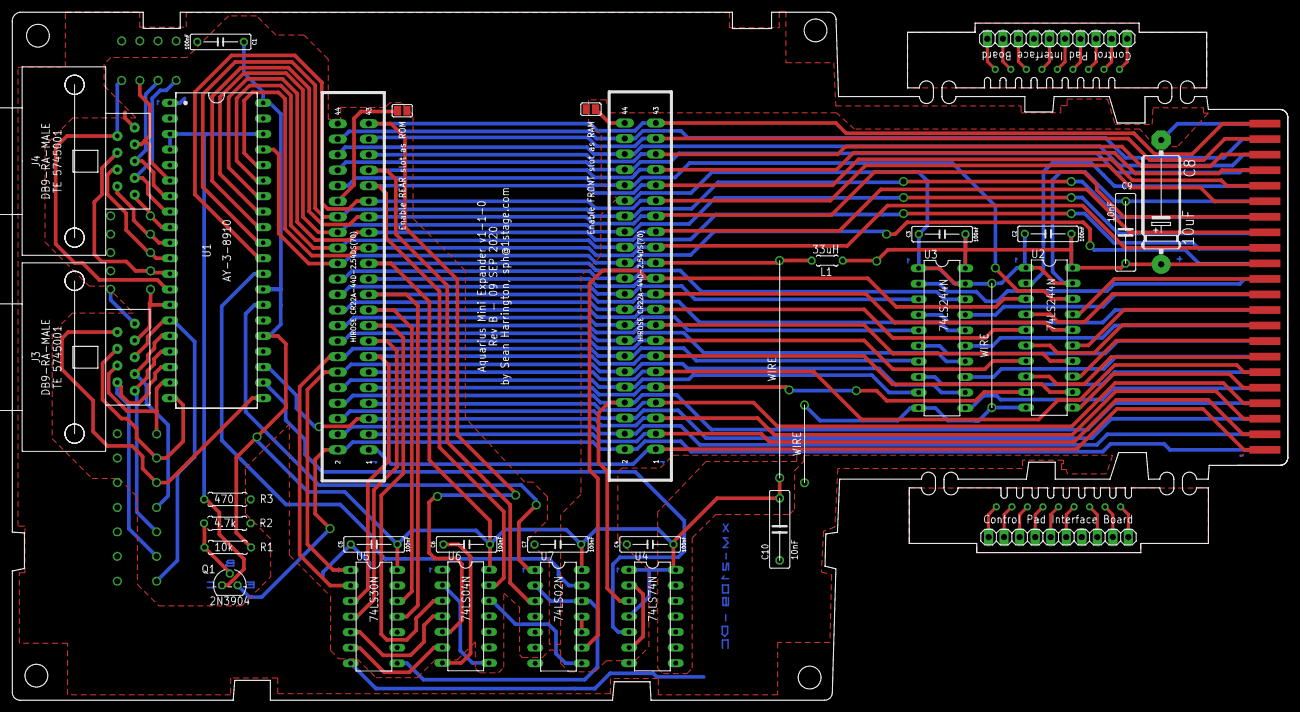
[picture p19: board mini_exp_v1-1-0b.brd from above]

Board: 2 copper layers, 208.6 x 112.5 mm, 34 parts (0 on the bottom side), 91 nets.

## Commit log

2020-08-27 First full push
    [mini_exp_v1-1-0a.brd, mini_exp_v1-1-0a.sch]
2020-09-03 Post PCB check edits
    [mini_exp_v1-1-0a.brd, mini_exp_v1-1-0a.sch]
2020-09-03 Clean up, post PCB arrival
    [mini_exp_v1-1-0b.brd, mini_exp_v1-1-0b.sch]
2020-09-09 Added Control Pad interface boards, updated board PDF, updated schematic PDF
    [mini_exp_v1-1-0b.brd, mini_exp_v1-1-0b.sch]
2020-09-28 Post-launch clean up
    [controller_circuit_01b_for_CUT.dxf]
2020-09-28 Updated STL file for MM units (Cura default)
    [mini_expander_case_BOTTOM.stl]
2020-10-05 Another update
    [mini_exp_v1-1-0b.brd]
2020-10-14 Added DIY Control Paad
    [control_pad_v1-2-0a.brd, control_pad_v1-2-0a.sch, diy_cp_base.stl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]
2020-10-14 Fixed DIY Control Pad file naming
    [control_pad_v1-1-0x.brd, control_pad_v1-1-0x.sch]
2020-10-14 Organize files into folders
    [control_pad_v1-1-0x.brd, control_pad_v1-1-0x.sch, diy_cp_base.stl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]
2020-10-15 set default units to mm
    [diy_cp_base.stl, diy_cp_buttons.stl, diy_cp_disc.stl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]
2021-02-08 Post publishing clean up, Add Rev C
    [control_pad_v1-1-0x.brd, control_pad_v1-1-0x.sch, mini_exp_v1-1-0c.brd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]
2021-02-09 Added IO Header to Rev C
    [mini_exp_v1-1-0c.brd, mini_exp_v1-1-0c.sch]
